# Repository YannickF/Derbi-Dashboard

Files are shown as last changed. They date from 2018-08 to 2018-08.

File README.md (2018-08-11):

# Derbi-Dashboard
Tableau de bord pour moto 50 cm3 Derbi Senda (ou "équivalent)

Le circuit imprimé est le même pour les 3 parties, mais il y a eu quelques oublis
Compteur en 3 parties indépendantes, chacune avec un écran OLED 1.3''
- compteur de vitesse (capteure inductif fixé sur la fourche et qui détecte le passage des têtes de vis du disque de frein). Le compteur kilométrique est stockéen EEPROM. Le compteur journalier est remis à zéro à chaque démarrage)
- compte-tours : fil issu de l'alternateur, avec diode de redressement
- voyants : phares / clignotants / niveau huile (flotteur installé dans le réservoir) / température / essence (avec le capteur d'origine toujours cablé avec son ampoule car il ne fonctionne pas sans)

Oublis sur le circuit imprimé : 
- diviseur de tension par 2 (2 résistances de 10 kohms) sur le fil du feu de route

REMARQUE : le circuit électrique de la moto a été légèrement modifié
- le 12V alternatif (pour les feux) est maintenant sur le 12V issu du régulateur (l'éclairage est stable même au ralenti)
- le 12 alternatif est utilisé pour le compte-tour mais il est redressé simple alternance (une diode) avant d'aller au tableau de bord. Ce signal n'est pas assez propre au ralenti pour être exploité mais il va très bien pour le reste du temps.
- le capteur de niveau d'huile n'est plus utilisé, un flotteur (on/off) est installé sur le bocal (on peut sans doute s'inspirer de la gestion du niveau d'essence pour faire fonctionner le capteur d'origine)

FONCTIONNEMENT DES CAPTEURS
Les capteurs d'huile et d'essence ne fonctionnent pas sans l'ampoule.
Pour l'essence, j'ai mesuré les tensions suivantes (mesurées entre la masse et le point milieu)
  - réservoir vide : environ 5 à 6 V (ce qui laisse 6V pour l'ampoule qui brille un peu)
  - réservoir plein : environ 8 V (il reste donc 4V pour l'ampoule, ce qui est insuffisant)

+12V. ---------
              |
              |
            Ampoule
              |
              |----------------- mesure de la tension
              |
            Capteur
              |
              |
 0V -----------

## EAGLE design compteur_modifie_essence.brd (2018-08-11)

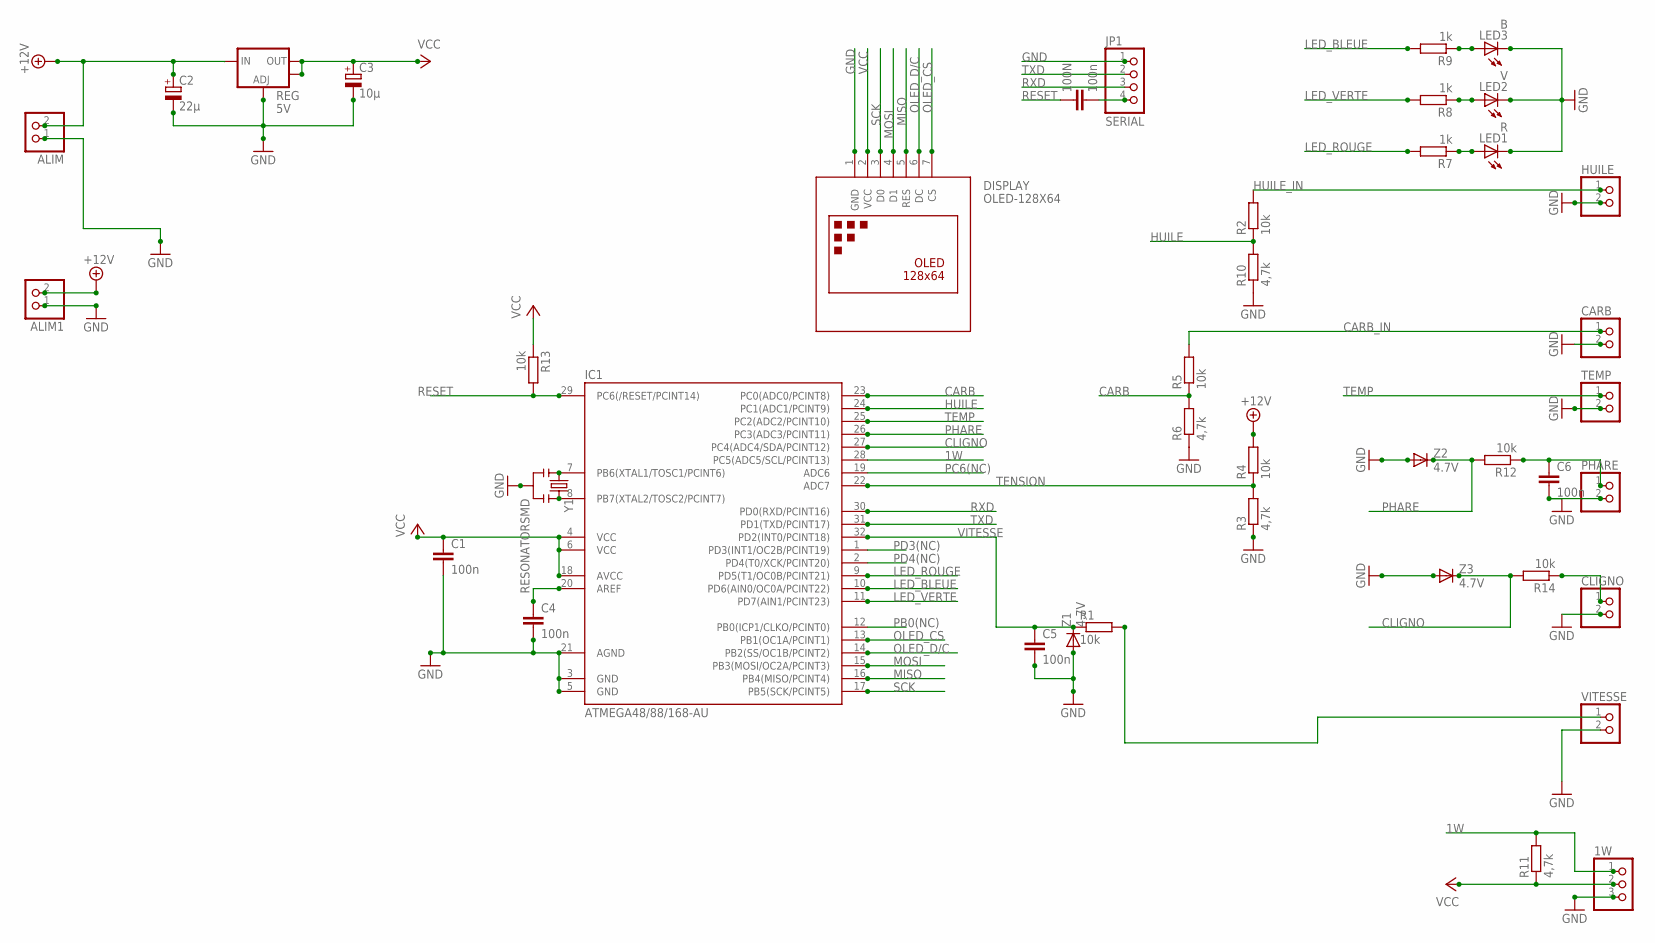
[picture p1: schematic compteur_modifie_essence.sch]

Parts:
1W: PINHD-1X3CB; 1X03-CLEANBIG
100N: 100n; C1206
ALIM, ALIM1: PINHD-1X2; 1X02
C1, C4, C5, C6: 100n; C1206
C2: 22µ; SMC_D
C3: 10µ; SMC_C
CARB: PINHD-1X2; 1X02
CLIGNO: PINHD-1X2; 1X02
DISPLAY: OLED-128X64; DISPLAY-OLED-128X64
HUILE: PINHD-1X2; 1X02
IC1: ATMEGA48/88/168-AU; TQFP32-08
JP1: SERIAL; 1X04_ROUND
LED1: R; LED5MM
LED2: V; LED5MM
LED3: B; LED5MM
PHARE: PINHD-1X2; 1X02
R1, R2, R4, R5, R12, R13, R14: 10k; R1206
R3, R6, R10, R11: 4,7k; R1206
R7, R8, R9: 1k; R1206
REG: 5V; SOT223
TEMP: PINHD-1X2; 1X02
VITESSE: PINHD-1X2; 1X02
Y1: RESONATORSMD; RESONATOR-SMD
Z1, Z2, Z3: 4.7V; SOD123

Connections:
1W: 1W.1, IC1.28 (PC5(ADC5/SCL/PCINT13)), R11.2
+12V: ALIM.2, ALIM1.2, C2.+, R4.2, REG.3 (IN)
AREF: C4.1, IC1.20 (AREF)
CARB: IC1.23 (PC0(ADC0/PCINT8)), R5.1, R6.2
CARB_IN: CARB.1, R5.2
CLIGNO: IC1.27 (PC4(ADC4/SDA/PCINT12)), R14.2, Z3.C
GND: 1W.3, ALIM.1, ALIM1.1, C1.2, C2.-, C3.-, C4.2, C5.2, C6.2, CARB.2, CLIGNO.2, DISPLAY.1 (GND), HUILE.2, IC1.3 (GND), IC1.5 (GND), IC1.21 (AGND), JP1.1, LED1.K (C), LED2.K (C), LED3.K (C), PHARE.2, R3.1, R6.1, R10.1, REG.1 (ADJ), TEMP.2, VITESSE.2, Y1.2, Z1.A, Z2.A, Z3.A
HUILE: IC1.24 (PC1(ADC1/PCINT9)), R2.1, R10.2
HUILE_IN: HUILE.1, R2.2
LED_BLEUE: IC1.10 (PD6(AIN0/OC0A/PCINT22)), R9.2
LED_ROUGE: IC1.9 (PD5(T1/OC0B/PCINT21)), R7.2
LED_VERTE: IC1.11 (PD7(AIN1/PCINT23)), R8.2
MISO: DISPLAY.5 (RES), IC1.16 (PB4(MISO/PCINT4))
MOSI: DISPLAY.4 (D1), IC1.15 (PB3(MOSI/OC2A/PCINT3))
unnamed: LED1.A, R7.1
unnamed: CLIGNO.1, R14.1
OLED_CS: DISPLAY.7 (CS), IC1.13 (PB1(OC1A/PCINT1))
OLED_D/C: DISPLAY.6 (DC), IC1.14 (PB2(SS/OC1B/PCINT2))
PB0(NC): IC1.12 (PB0(ICP1/CLKO/PCINT0))
PC6(NC): IC1.19 (ADC6)
PD3(NC): IC1.1 (PD3(INT1/OC2B/PCINT19))
PD4(NC): IC1.2 (PD4(T0/XCK/PCINT20))
PHARE: IC1.26 (PC3(ADC3/PCINT11)), R12.2, Z2.C
PHARE_IN: C6.1, PHARE.1, R12.1
R8: LED2.A, R8.1
R9: LED3.A, R9.1
RESET: 100N.1, IC1.29 (PC6(/RESET/PCINT14)), R13.2
RST: 100N.2, JP1.4
RXD: IC1.30 (PD0(RXD/PCINT16)), JP1.3
SCK: DISPLAY.3 (D0), IC1.17 (PB5(SCK/PCINT5))
TEMP: IC1.25 (PC2(ADC2/PCINT10)), TEMP.1
TENSION: IC1.22 (ADC7), R3.2, R4.1
TXD: IC1.31 (PD1(TXD/PCINT17)), JP1.2
VCC: 1W.2, C1.1, C3.+, DISPLAY.2 (VCC), IC1.4 (VCC), IC1.6 (VCC), IC1.18 (AVCC), R11.1, R13.1, REG.2 (OUT), REG.4 (OUT)
VITESSE: C5.1, IC1.32 (PD2(INT0/PCINT18)), R1.1, Z1.C
VITESS_IN: R1.2, VITESSE.1
XTAL1: IC1.7 (PB6(XTAL1/TOSC1/PCINT6)), Y1.1
XTAL2: IC1.8 (PB7(XTAL2/TOSC2/PCINT7)), Y1.3

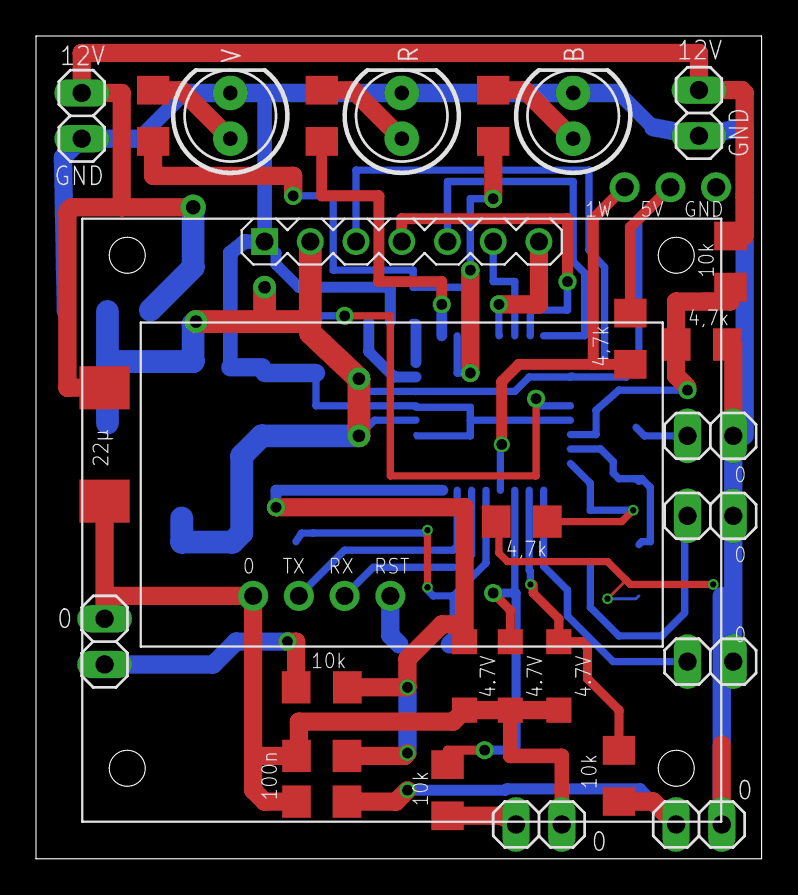
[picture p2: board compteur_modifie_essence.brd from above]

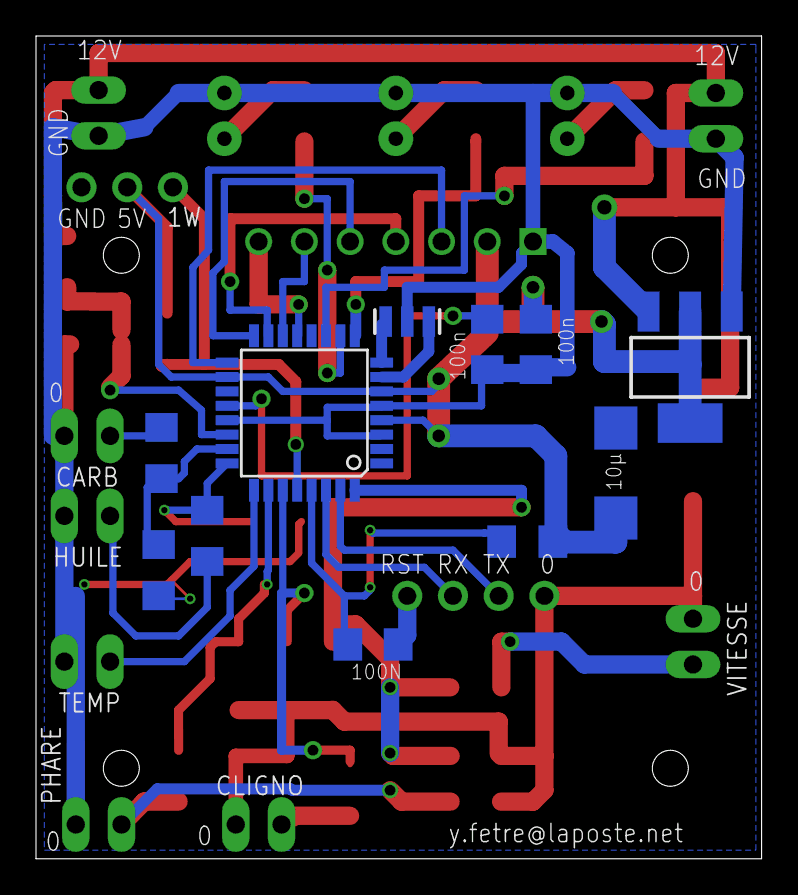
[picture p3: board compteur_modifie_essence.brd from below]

Board: 2 copper layers, 40.3 x 45.7 mm, 41 parts (12 on the bottom side), 34 nets.

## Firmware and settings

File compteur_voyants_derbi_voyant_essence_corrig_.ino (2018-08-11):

#include <Arduino.h>
#include <SPI.h>
#include <U8g2lib.h>
#include <avr/interrupt.h>
#include <OneWire.h>

#define MAX_TEMP 30 // temperature maximum pour le capteur 1W -> allumera le voyant si valeur dépassée
#define BATT_MAX 15.0  //tension maxi de la batterie
#define BATT_MIN 10.5  //tension mini de la batterie
#define ALLUME_ESSENCE_VIDE 550 // niveau du convertisseur Analogique numerique qui permet de basculer le voyant d'essence sur ON ou OFF
#define ALLUME_ESSENCE_PLEIN 750 // niveau d'essence PLEIN

#define pin_tension 7
#define pin_phare    A3
#define pin_cligno   A4
#define pin_essence  0
#define pin_huile    A1
#define pin_eau      A2
#define led_rouge    5
#define led_bleue    6
#define led_verte    7
#define BROCHE_ONEWIRE A5

//#define TEMPERATURE   //presence d'une sonde DS18B20
//#define DEBUG

//Pour l'huile, la température d'eau et le carburant, il y a de temps en temps des allumage intempestifs
// si le nombre de micro-allumages des voyants (consécutifs) atteint cette valeur, alors le voyant sera allumée pour de bon
#define COMPT_VOYANT_huile_MAX 20
#define COMPT_VOYANT_eau_MAX 20
#define COMPT_VOYANT_essence_MAX 20
#define COMPT_VOYANT_batt_MAX 20
unsigned char COMPT_VOYANT_huile=0;
unsigned char COMPT_VOYANT_eau=0;
unsigned char COMPT_VOYANT_essence=0;
unsigned char COMPT_VOYANT_batt=0;


/* Code de retour de la fonction getTemperature() */
enum DS18B20_RCODES {
  READ_OK,  // Lecture ok
  NO_SENSOR_FOUND,  // Pas de capteur
  INVALID_ADDRESS,  // Adresse reçue invalide
  INVALID_SENSOR  // Capteur invalide (pas un DS18B20)
};
/* Création de l'objet OneWire pour manipuler le bus 1-Wire */
OneWire ds(BROCHE_ONEWIRE);


unsigned int temp=0;
float tension=0;
float temperature=0;
float essence_f=0; // valeur pour mesurer le "niveau" d'essence (le capteur associé à l'ampoule donne une tension en fonction du niveau, il faut donc utiliser le convertisseur analogique/numerique
signed int temperature_int=0;
boolean phare = false;
boolean cligno = false;
boolean essence = false;
boolean essence_pre_alerte = false;
boolean huile= false;
boolean capt_eau=false;
boolean eau = false;
boolean batterie = false;
boolean aff_alertes=false;  // pour faire clignoter les icones

#define huile_width 40
#define huile_height 20
static unsigned char huile_bits[] = {
   0x00, 0x00, 0x00, 0x00, 0x00, 0x00, 0x00, 0x00, 0x00, 0x00, 0x00, 0x00,
   0x00, 0x00, 0x00, 0x00, 0x00, 0x00, 0x00, 0x00, 0x38, 0x00, 0x00, 0x00,
   0x00, 0xec, 0x01, 0x00, 0x00, 0x00, 0x86, 0xf7, 0x07, 0x00, 0x02, 0x06,
   0xc6, 0x00, 0x80, 0x0f, 0x3c, 0xfe, 0x1f, 0xe0, 0x0f, 0xe0, 0xfe, 0x3f,
   0xf8, 0x01, 0x80, 0xff, 0x7f, 0xde, 0x10, 0x00, 0x06, 0xe0, 0x67, 0x10,
   0x00, 0x06, 0xc0, 0x31, 0x38, 0x00, 0x06, 0x80, 0x18, 0x38, 0x00, 0x06,
   0x00, 0x0c, 0x38, 0x00, 0x06, 0x00, 0x06, 0x00, 0x00, 0xfe, 0xff, 0x03,
   0x00, 0x00, 0xfe, 0xff, 0x01, 0x00, 0x00, 0x00, 0x00, 0x00, 0x00, 0x00,
   0x00, 0x00, 0x00, 0x00 };
#define eau_width 31
#define eau_height 31
static unsigned char eau_bits[] = {
   0x00, 0x00, 0x00, 0x00, 0x00, 0x80, 0x00, 0x00, 0x00, 0xc0, 0x01, 0x00,
   0x00, 0xc0, 0x01, 0x00, 0x00, 0xc0, 0x01, 0x00, 0x00, 0xc0, 0xff, 0x00,
   0x00, 0xc0, 0xff, 0x00, 0x00, 0xc0, 0x01, 0x00, 0x00, 0xc0, 0x01, 0x00,
   0x00, 0xc0, 0x01, 0x00, 0x00, 0xc0, 0xff, 0x00, 0x00, 0xc0, 0xff, 0x00,
   0x00, 0xc0, 0x01, 0x00, 0x00, 0xc0, 0x01, 0x00, 0x00, 0xc0, 0x01, 0x00,
   0x00, 0xc0, 0xff, 0x00, 0x00, 0xc0, 0xff, 0x00, 0x00, 0xc0, 0x01, 0x00,
   0x00, 0xc0, 0x01, 0x00, 0x08, 0xc0, 0x01, 0x08, 0x3e, 0xe2, 0x23, 0x3e,
   0xff, 0xf3, 0xe7, 0x7f, 0xc3, 0xf3, 0xe7, 0x63, 0x00, 0xe0, 0x03, 0x00,
   0x00, 0xc0, 0x01, 0x00, 0x08, 0x08, 0x08, 0x08, 0x1c, 0x1c, 0x1c, 0x1c,
   0xfc, 0xff, 0xff, 0x1f, 0xe0, 0xe3, 0xe3, 0x03, 0x80, 0x80, 0x80, 0x00,
   0x00, 0x00, 0x00, 0x00 };
#define essence_width 30
#define essence_height 30
static unsigned char essence_bits[] = {
   0x00, 0x00, 0x00, 0x00, 0x00, 0x00, 0x00, 0x00, 0xf0, 0xff, 0xf7, 0x01,
   0xf0, 0xff, 0xc7, 0x03, 0xf0, 0xff, 0x87, 0x07, 0x30, 0x00, 0x06, 0x07,
   0x30, 0x00, 0x06, 0x0f, 0x30, 0x00, 0x86, 0x0f, 0x30, 0x00, 0x86, 0x0f,
   0x30, 0x00, 0x06, 0x0f, 0x30, 0x00, 0x06, 0x0e, 0x30, 0x00, 0x7e, 0x0e,
   0x70, 0x00, 0x7f, 0x0e, 0xf0, 0xff, 0xe7, 0x0e, 0xf0, 0xff, 0xe7, 0x0e,
   0xf0, 0xff, 0xe7, 0x0e, 0xf0, 0xff, 0xe7, 0x0e, 0xf0, 0xff, 0xe7, 0x0e,
   0xf0, 0xff, 0xe7, 0x0e, 0xf0, 0xff, 0xe7, 0x0e, 0xf0, 0xff, 0xe7, 0x0e,
   0xf0, 0xff, 0xe7, 0x0e, 0xf0, 0xff, 0xe7, 0x0e, 0xf0, 0xff, 0xe7, 0x0f,
   0xf0, 0xff, 0xc7, 0x07, 0xf8, 0xff, 0x0f, 0x01, 0xfc, 0xff, 0x1f, 0x00,
   0xfc, 0xff, 0x1f, 0x00, 0x00, 0x00, 0x00, 0x00, 0x00, 0x00, 0x00, 0x00 };

#define cligno_width 40
#define cligno_height 26
static unsigned char cligno_bits[] = {
   0x00, 0x00, 0x00, 0x00, 0x00, 0x00, 0x00, 0x00, 0x00, 0x00, 0x00, 0x00,
   0x00, 0x00, 0x00, 0x00, 0x0c, 0x00, 0x30, 0x00, 0x00, 0x0e, 0x00, 0x70,
   0x00, 0x00, 0x0f, 0x00, 0xf0, 0x00, 0x80, 0xfd, 0xc3, 0xbf, 0x01, 0xc0,
   0xfc, 0xc3, 0x3f, 0x03, 0x60, 0x00, 0x42, 0x00, 0x06, 0x30, 0x00, 0x42,
   0x00, 0x0c, 0x18, 0x00, 0x42, 0x00, 0x18, 0x0c, 0x00, 0x42, 0x00, 0x30,
   0x06, 0x00, 0x42, 0x00, 0x60, 0x06, 0x00, 0x42, 0x00, 0x60, 0x0c, 0x00,
   0x42, 0x00, 0x30, 0x18, 0x00, 0x42, 0x00, 0x18, 0x30, 0x00, 0x42, 0x00,
   0x0c, 0x60, 0x00, 0x42, 0x00, 0x06, 0xc0, 0xfc, 0xc3, 0x3f, 0x03, 0x80,
   0xfd, 0xc3, 0xbf, 0x01, 0x00, 0x0f, 0x00, 0xf0, 0x00, 0x00, 0x0e, 0x00,
   0x70, 0x00, 0x00, 0x0c, 0x00, 0x30, 0x00, 0x00, 0x00, 0x00, 0x00, 0x00,
   0x00, 0x00, 0x00, 0x00, 0x00, 0x00, 0x00, 0x00, 0x00, 0x00 };
#define phare_width 40
#define phare_height 29
static unsigned char phare_bits[] = {
   0x00, 0x00, 0x00, 0x00, 0x00, 0x00, 0x00, 0x80, 0x03, 0x00, 0x00, 0x00,
   0xe0, 0x0f, 0x00, 0xfc, 0x3f, 0xf8, 0x7f, 0x00, 0xfc, 0x3f, 0x3c, 0xf8,
   0x01, 0x00, 0x00, 0x1e, 0xe0, 0x03, 0x00, 0x00, 0x06, 0x80, 0x07, 0x00,
   0x00, 0x06, 0x00, 0x0f, 0xfc, 0x3f, 0x07, 0x00, 0x1c, 0xfc, 0x3f, 0x07,
   0x00, 0x1c, 0x00, 0x00, 0x03, 0x00, 0x38, 0x00, 0x00, 0x03, 0x00, 0x30,
   0x00, 0x00, 0x03, 0x00, 0x30, 0xfc, 0x3f, 0x03, 0x00, 0x30, 0xfc, 0x3f,
   0x03, 0x00, 0x30, 0x00, 0x00, 0x03, 0x00, 0x30, 0x00, 0x00, 0x03, 0x00,
   0x38, 0x00, 0x00, 0x03, 0x00, 0x18, 0xfc, 0x3f, 0x07, 0x00, 0x1c, 0xfc,
   0x3f, 0x07, 0x00, 0x0e, 0x00, 0x00, 0x06, 0x00, 0x07, 0x00, 0x00, 0x0e,
   0xc0, 0x03, 0x00, 0x00, 0x1c, 0xf8, 0x01, 0xfc, 0x3f, 0xf8, 0x7f, 0x00,
   0xfc, 0x3f, 0xf0, 0x1f, 0x00, 0x00, 0x00, 0x00, 0x00, 0x00, 0x00, 0x00,
   0x00, 0x00, 0x00, 0x00, 0x00, 0x00, 0x00, 0x00, 0x00, 0x00, 0x00, 0x00,
   0x00 };
#define croisement_width 40
#define croisement_height 29
static unsigned char croisement_bits[] = {
   0x00, 0x00, 0x00, 0x00, 0x00, 0x00, 0x00, 0x80, 0x03, 0x00, 0x00, 0x00,
   0xe0, 0x0f, 0x00, 0x00, 0x38, 0xf8, 0x7f, 0x00, 0x00, 0x3e, 0x3c, 0xf8,
   0x01, 0xc0, 0x0f, 0x1e, 0xe0, 0x03, 0xf0, 0x03, 0x06, 0x80, 0x07, 0x7c,
   0x00, 0x06, 0x00, 0x0f, 0x0e, 0x38, 0x07, 0x00, 0x1c, 0x00, 0x3e, 0x07,
   0x00, 0x1c, 0xc0, 0x0f, 0x03, 0x00, 0x38, 0xf0, 0x03, 0x03, 0x00, 0x30,
   0x7c, 0x00, 0x03, 0x00, 0x30, 0x0e, 0x38, 0x03, 0x00, 0x30, 0x00, 0x3e,
   0x03, 0x00, 0x30, 0xc0, 0x0f, 0x03, 0x00, 0x30, 0xf0, 0x03, 0x03, 0x00,
   0x38, 0x7c, 0x00, 0x03, 0x00, 0x18, 0x0e, 0x38, 0x07, 0x00, 0x1c, 0x00,
   0x3e, 0x07, 0x00, 0x0e, 0xc0, 0x0f, 0x06, 0x00, 0x07, 0xf0, 0x03, 0x0e,
   0xc0, 0x03, 0x7c, 0x00, 0x1c, 0xf8, 0x01, 0x0e, 0x38, 0xf8, 0x7f, 0x00,
   0x00, 0x3e, 0xf0, 0x1f, 0x00, 0xc0, 0x0f, 0x00, 0x00, 0x00, 0xf0, 0x03,
   0x00, 0x00, 0x00, 0x7c, 0x00, 0x00, 0x00, 0x00, 0x0e, 0x00, 0x00, 0x00,
   0x00 };
#define batterie_width 28
#define batterie_height 21
static unsigned char batterie_bits[] = {
   0x00, 0x00, 0x00, 0x00, 0x00, 0x00, 0x00, 0x00, 0xe0, 0x01, 0x78, 0x00,
   0xe0, 0x01, 0x78, 0x00, 0xe0, 0x01, 0x78, 0x00, 0xfc, 0xff, 0xff, 0x03,
   0xfc, 0xff, 0xff, 0x03, 0xfc, 0xff, 0xff, 0x03, 0xfc, 0xff, 0xff, 0x03,
   0xfc, 0xff, 0xcf, 0x03, 0xfc, 0xff, 0xcf, 0x03, 0x0c, 0xfc, 0x03, 0x03,
   0x0c, 0xfc, 0x03, 0x03, 0xfc, 0xff, 0xcf, 0x03, 0xfc, 0xff, 0xcf, 0x03,
   0xfc, 0xff, 0xff, 0x03, 0xfc, 0xff, 0xff, 0x03, 0xfc, 0xff, 0xff, 0x03,
   0xfc, 0xff, 0xff, 0x03, 0x00, 0x00, 0x00, 0x00, 0x00, 0x00, 0x00, 0x00 };





/* Constructor */
U8G2_SH1106_128X64_NONAME_1_4W_HW_SPI u8g2(U8G2_R0, /* cs=*/ 9, /* dc=*/ 10, /* reset=*/ 12);  //CS non connecté en réalité



/* u8g2.begin() is required and will sent the setup/init sequence to the display */
void setup(void) {
#ifdef DEBUG
  Serial.begin(57600);  // meme débit que le bootloader (old)
#endif
  // configuration des broches en entrées / sorties
  analogReference(DEFAULT);
  pinMode(pin_tension,INPUT);
  pinMode(pin_phare,INPUT);
  pinMode(pin_cligno,INPUT);
  pinMode(pin_essence,INPUT);
  pinMode(pin_huile,INPUT_PULLUP);
  pinMode(pin_eau,INPUT_PULLUP);
  pinMode(led_rouge,OUTPUT);
  pinMode(led_bleue,OUTPUT);
  pinMode(led_verte,OUTPUT);

  // réduction de la résolution du DS18B20
  setResolution9bits();

  // paramétrage de l'écran OLED
  u8g2.begin();
  // animation de boot
  for (int i=0;i<65;i++) {
    u8g2.firstPage();
    do {
      u8g2.drawBox(64-i,0,2*i,64);
    } while ( u8g2.nextPage() );
  }
  for (int i=65;i>=0;i--) {
    u8g2.firstPage();
    do {
      u8g2.drawBox(64-i,0,2*i,64);
    } while ( u8g2.nextPage() );
  }


  // test des LED
  digitalWrite(led_verte,HIGH);
  delay(250);
  digitalWrite(led_rouge,HIGH);
  delay(250);
  digitalWrite(led_bleue,HIGH);
  delay(500);
  digitalWrite(led_bleue,LOW);
  delay(250);
  digitalWrite(led_rouge,LOW);
  delay(250);
  digitalWrite(led_verte,LOW);
}

/* draw something on the display with the `firstPage()`/`nextPage()` loop*/
void loop(void) {
#ifdef TEMPERATURE
   // Lecture de la température via sonde DS18B20
   if (getTemperature(&temperature, true) != READ_OK) {
     temperature=-99;
      return;
   }
#else
  temperature=99;
#endif

   //  lecture de la tension, on fait la moyenne sur 16 lectures
   temp=0;
   for (char i=0;i<=15;i++) {
    temp+=analogRead(pin_tension);
   }
   tension=(float) (temp / 16)  ;
   tension = tension* 0.015272;  // c'est le coefficient du convertisseur ADC

  //  lecture du niveau d'essence, on fait la moyenne sur 16 lectures (on pourrait le faire en même temps que pour la tension)
   temp=0;
   for (char i=0;i<=15;i++) {
    temp+=analogRead(pin_essence); 
   }
   essence_f=(float) (temp / 16)  ;
   if (essence_f <= ALLUME_ESSENCE_VIDE) {essence=true; essence_pre_alerte=false;}
   else if (essence_f >= ALLUME_ESSENCE_PLEIN) {essence=false; essence_pre_alerte=false;}
   else {essence=false; essence_pre_alerte=true;}
   
 #ifdef DEBUG
  Serial.print("Essence : ");
  Serial.println(essence_f);
  Serial.print("Alerte : ");
  Serial.println(essence);
  Serial.print("Pre-Alerte : ");
  Serial.println(essence_pre_alerte);
  Serial.println();
 #endif
  // lecture des états des broches
  phare=digitalRead(pin_phare);
  cligno=digitalRead(pin_cligno);
  //essence=!digitalRead(pin_essence);
  huile=!digitalRead(pin_huile);
  capt_eau=!digitalRead(pin_eau);

  // TEST pour éviter les déclenchement intempestifs des alertes
  if (essence) {
    COMPT_VOYANT_essence++;
    if (COMPT_VOYANT_essence < COMPT_VOYANT_essence_MAX) {essence=false;}
  }
  else {
    COMPT_VOYANT_essence=0;
  }
  if (huile) {
    COMPT_VOYANT_huile++;
    if (COMPT_VOYANT_huile < COMPT_VOYANT_huile_MAX) {huile=false;}
  }
  else {
    COMPT_VOYANT_huile=0;
  }
  if (capt_eau) {
    COMPT_VOYANT_eau++;
    if (COMPT_VOYANT_eau < COMPT_VOYANT_eau_MAX) {capt_eau=false;}
  }
  else {
    COMPT_VOYANT_eau=0;
  }
  if ((tension > BATT_MAX) or (tension < BATT_MIN)) {
    COMPT_VOYANT_batt++;
    batterie=true;
    if (COMPT_VOYANT_batt < COMPT_VOYANT_batt_MAX) {batterie=false;}
  }
  else {
    COMPT_VOYANT_batt=0;
    batterie=false;
  }

  // TEST POUR DECLENCHER LES ALERTES sur les LED
  if (phare) {digitalWrite(led_bleue,HIGH);} else {digitalWrite(led_bleue, LOW);}
  if (cligno) {digitalWrite(led_verte,HIGH);} else {digitalWrite(led_verte, LOW);}
  if (essence or huile or eau  or batterie) {digitalWrite(led_rouge,HIGH);} else {digitalWrite(led_rouge, LOW);} 
  // on n'allume pas la LED rouge en cas de pré-alerte essence
  if (capt_eau or (temperature_int >= MAX_TEMP)) {eau=true;} else {eau=false;}


  // AFFICHAGE SUR L'ECRAN
  u8g2.firstPage();
  do {
    // quadrillage
    u8g2.drawHLine(0,32,128);
    u8g2.drawVLine(42,0,64);
    u8g2.drawVLine(85,0,64);

    // affichage de la tension et de la température (sauf si voyant de batterie)
    if (batterie and aff_alertes)
    {
      u8g2.drawXBM( 50, 5, batterie_width, batterie_height, batterie_bits);
    }
    else
    {
      u8g2.setFont(u8g2_font_courB08_tf);
      u8g2.drawStr(77, 11, "V");
#ifdef TEMPERATURE
      u8g2.drawUTF8(72,26,"°C");
#endif
      u8g2.setCursor(47,11);
      u8g2.print(tension,1);
      u8g2.setCursor(55,26);
#ifdef TEMPERATURE
      temperature_int=(int) int(temperature);  // on ne garde que la partie entière de la température
      u8g2.print(temperature_int);
#endif
    }

    // affichage huile
    if (huile and aff_alertes) {u8g2.drawXBM( 44, 38, huile_width, huile_height, huile_bits);}
    // affichage eau
    if (eau and aff_alertes) {u8g2.drawXBM( 92, 33, eau_width, eau_height, eau_bits);}
    // affichage pre alerte essence (sans clignoter)
    if (essence_pre_alerte) {u8g2.drawXBM( 5, 33, essence_width, essence_height, essence_bits);}
    // affichage essence
    if (essence and aff_alertes) {u8g2.drawXBM( 5, 33, essence_width, essence_height, essence_bits);}
    //affichage cligno
    if (cligno==true) {u8g2.drawXBM( 88, 3, cligno_width, cligno_height, cligno_bits);}
    //affichage phare/croisement
    if (phare==true) {u8g2.drawXBM( 1, 1, phare_width, phare_height, phare_bits);}
    else {u8g2.drawXBM( 1, 1, croisement_width, croisement_height, croisement_bits);}
  } while ( u8g2.nextPage() );

  // on fait clignoter les voyants
  aff_alertes=!aff_alertes;
  delay(100);





}


void setResolution9bits(void) {
  byte addr[8];
  // data[] : Données lues depuis le scratchpad
  // addr[] : Adresse du module 1-Wire détecté
  ds.search(addr);
  if (addr[0] == 0x28)   // on verifie que c'est un DS18B20
  {
    Serial.print("C'est bien un DS18B20");
    // Réduction de la résolution du capteur à 9 bits
    ds.reset(); // rest 1-Wire
    ds.select(addr); // select DS18B20
    ds.write(0x4E); // write on scratchPad
    ds.write(0x00); // User byte 0 - Unused
    ds.write(0x00); // User byte 1 - Unused
    ds.write(0x1F); // set up en 9 bits (0x1F)
    ds.reset(); // reset 1-Wire
  }
}

/**
 * Fonction de lecture de la température via un capteur DS18B20.
 */
byte getTemperature(float *temperature, byte reset_search) {
  byte data[9], addr[8];
  // data[] : Données lues depuis le scratchpad
  // addr[] : Adresse du module 1-Wire détecté

  /* Reset le bus 1-Wire ci nécessaire (requis pour la lecture du premier capteur) */
  if (reset_search) {
    ds.reset_search();
  }

  /* Recherche le prochain capteur 1-Wire disponible */
  if (!ds.search(addr)) {
    // Pas de capteur
    return NO_SENSOR_FOUND;
  }

  /* Vérifie que l'adresse a été correctement reçue */
  if (OneWire::crc8(addr, 7) != addr[7]) {
    // Adresse invalide
    return INVALID_ADDRESS;
  }

  /* Vérifie qu'il s'agit bien d'un DS18B20 */
  if (addr[0] != 0x28) {
    // Mauvais type de capteur
    return INVALID_SENSOR;
  }




  /* Reset le bus 1-Wire et sélectionne le capteur */
  ds.reset();
  ds.select(addr);

  /* Lance une prise de mesure de température et attend la fin de la mesure
      On attend 100 ms au lieu de 800 puisqu'on a réduit la résolution et que cela réduit le temps de conversion
  */
  ds.write(0x44, 1);
  delay(100);

  /* Reset le bus 1-Wire, sélectionne le capteur et envoie une demande de lecture du scratchpad */
  ds.reset();
  ds.select(addr);
  ds.write(0xBE);

 /* Lecture du scratchpad */
  for (byte i = 0; i < 9; i++) {
    data[i] = ds.read();
  }

  /* Calcul de la température en degré Celsius */
  *temperature = ((data[1] << 8) | data[0]) * 0.0625;

  // Pas d'erreur
  return READ_OK;
}

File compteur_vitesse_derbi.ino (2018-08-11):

#include <Arduino.h>
#include <SPI.h>
#include <U8g2lib.h>
#include <avr/interrupt.h>
#include <EEPROM.h>

//#define DEBUG
// choix entre 2 modes de mesure de la rotation de la roue
// DETECTE_TIERS_DISQUE : on mesure un 1/3 de tour de roue grace au disque de frein (en 3 parties)
// DETECTE_TIERS_2_TETES_VIS : on mesure 1/3 de tour de roue grace au 6 vis de fixation du disque (3 paires de vis) : il y a donc des impulsions supplémentaires à gérer
#define DETECTE_TIERS_DISQUE
//#define DETECTE_TIERS_2_TETES_VIS


// pour programmer initialement le total kilométrique à la valeur de l'ancien compteur à cable
// il faudra transférer le firmware 1 fois avec ce #define, puis ensuite sans. L'EEPROM sera alors programmée avec cette valeur.
//#define INIT_COMPTEUR 10580 

#define OCIEA 1    // ce bit du registre TIMSK1 est bizarrement non défini dans Arduino, alors qu'il est documenté dans la datasheet

// périmètre de la roue en mm
const float tour_roue = 2136;
const unsigned int pulse_1kmh = 40050; // nombre de pulse d'horloge correspondant à 1, à 99, et 0 km/havec les réglages du timer ci-dessous (dans setup)
const unsigned int pulse_99kmh = 405; 
const unsigned int pulse_0kmh = 65535;
#define input_pin 2   // broche d'entrée du signal pour le compteur

// les variables pour les compteurs : (vitesse, trip, km total)
volatile unsigned int vitesse=0;
volatile float trip = 0;
volatile float total = 0;
float old_total = 0;

// variables pour mesurer le temps entre 2 impulsions
volatile unsigned int pulse;
volatile byte compte_pulse = 0;
// variables pour bien positionner l'affichage des valeurs sur l'écran (en fonction du nombre de chiffres)
unsigned char pos_vitesse = 34;
unsigned char pos_total = 8;
unsigned char pos_trip = 75;


/* Constructor */
U8G2_SH1106_128X64_NONAME_1_4W_HW_SPI u8g2(U8G2_R0, /* cs=*/ 9, /* dc=*/ 10, /* reset=*/ 12);



void calcul_vitesse(void) {
    //calcul des vitesses
   if (pulse >=pulse_99kmh) {vitesse=pulse_1kmh / pulse;} // on evite la division par 0 en cas de débordement du timer (pulse vaut 0 dans ce cas)
    else {vitesse=99;}
    if (vitesse < 10) {
      pos_vitesse = 33;
    } else {
      pos_vitesse = 4;
    }

    //calcul du trip
    if (trip > 999.9) {
      trip = 0;
    }
    if (trip <= 9.9) {
      pos_trip = 86;
    }
    if (trip >= 10) {
      pos_trip = 80;
    }
    if (trip >= 100) {
      pos_trip = 74;
    }


    //calcul du total
    if (total > 99999) {
      total = 0;
    }
    if (total > 9) {
      pos_total = 23;
    } else {
      pos_total = 29;
    }
    if (total > 99) {
      pos_total = 17;
    }
    if (total > 999) {
      pos_total = 11;
    }
    if (total > 9999) {
      pos_total = 5;
    }
}



void input_pulse(void) {

#ifdef DETECTE_TIERS_2_TETES_VIS
  compte_pulse++;
  if (compte_pulse == 1) { // c'est la 1ère impulsion, on lance le timer1 à partir de 0
    TCNT1 = 0;
  }
  if (compte_pulse == 3) {
    pulse = TCNT1;
    compte_pulse = 0;
    trip += tour_roue / 3000000 ;  // conversion mm en km + facteur 1/3 car on compte les tiers de tours de roue
    total += tour_roue / 3000000;
  }
#endif
#ifdef DETECTE_TIERS_DISQUE
    pulse=TCNT1;
    TCNT1=0;
    trip += tour_roue / 3000000 ;  // conversion mm en km + facteur 1/3 car on compte les tiers de tours de roue
    total += tour_roue / 3000000;

#endif
#ifdef DEBUG
  Serial.print("Pulse ");
  Serial.print(compte_pulse);
  Serial.print(" : ");
  Serial.println(TCNT1);
  Serial.println(total);
  Serial.println(trip);
#endif
}

//ISR(TIMER1_OVF_vect) {
//#ifdef DEBUG
//  Serial.println("OVF !");
//#endif
//}

ISR(TIMER1_COMPA_vect) {
#ifdef DEBUG
  Serial.println("COMPA !");
#endif
  // on roule très lentement !!!!
  pulse = pulse_0kmh;
  compte_pulse = 0;
  // on en profite pour mémoriser les nouvelles données (compteur total) dans l'EEPROM
  // on mémorise le total s'il a augmenté de plus de 500 m
  EEPROM.get(0, old_total);
  if (total - old_total >= 0.5) {
    old_total = total;
    EEPROM.put(0, total);
  }
#ifdef INIT_COMPTEUR
  EEPROM.put(0, (float) INIT_COMPTEUR);
#endif

}

/* u8g2.begin() is required and will sent the setup/init sequence to the display */
void setup(void) {
#ifdef DEBUG
  Serial.begin(115200);
#endif
  // on lit le compteur kilométrique total en EEPROM (adresse 0)
  EEPROM.get(0, total);
  old_total = total;

  // paramétrage de l'écran OLED
  u8g2.begin();
  // animation de boot
  for (int i=0;i<65;i++) {
    u8g2.firstPage();
    do {
      u8g2.drawBox(64-i,0,2*i,64);
    } while ( u8g2.nextPage() );
  }
  for (int i=65;i>=0;i--) {
    u8g2.firstPage();
    do {
      u8g2.drawBox(64-i,0,2*i,64);
    } while ( u8g2.nextPage() );
  }

  // on active l'interruption sur débordement du timer1 par rapport au registre OCR1A (output compare)
  TCCR1B = 0;
  TCCR1A = 0;
  OCR1A =  pulse_1kmh;   // avec un quartz à 16 MHz et prescaler 1024, cette valeur va provoquer un overflow après 2,5632s, ce qui correspond à moins de 1 km/h avec la roue de 68 cm de diamètre (on mesure 1/3 de tour de roue)
  //TIMSK1 |= (1 << TOIE1) ;
  TIMSK1 |= (1 << OCIEA) ;
  // on active le mode 4 CTC (timer1 debord quand il atteint la valeur OCR1A)
  TCCR1B |= (1 << WGM12); // mode CTC 4
  // on divise la fréquence d'horloge par 1024 @ 16 MHz : 1 tic=64 µs
  TCCR1B |= (1 << CS12);
  TCCR1B |= (1 << CS10);
  
  TCNT1=0;
  // configuration entrée/sortie et interruption
  pinMode(input_pin, INPUT_PULLUP);
  attachInterrupt(digitalPinToInterrupt(input_pin), input_pulse, FALLING);

}

/* draw something on the display with the `firstPage()`/`nextPage()` loop*/
void loop(void) {

  


  // AFFICHAGE SUR L'ECRAN

  u8g2.firstPage();

  do {

    // affichage de l'unité de mesure de la vitesse
    u8g2.setFont(u8g2_font_logisoso16_tf);
    u8g2.drawStr(75, 17, "km/h");


    // affichage dela vitesse
    u8g2.setFont(u8g2_font_logisoso50_tn);
    u8g2.setCursor(pos_vitesse, 50);
    u8g2.print(vitesse);

    // affichage des unités des compteurs kilométriques
    u8g2.setFont(u8g2_font_courB08_tf);
    u8g2.drawStr(42, 64, "km");
    u8g2.drawStr(115, 64, "km");

    // affichage du trip
    u8g2.setCursor(pos_trip, 64);
    u8g2.print(trip);

    //affichage du total
    u8g2.setCursor(pos_total, 64);
    u8g2.print((unsigned int)total);

 #ifdef DEBUG
 // pour debug : affichage du la valeur pulse
    u8g2.setCursor(70, 32);
    u8g2.print((unsigned int)pulse);
 #endif
  } while ( u8g2.nextPage() );
 
  delay(750);
  calcul_vitesse();

}

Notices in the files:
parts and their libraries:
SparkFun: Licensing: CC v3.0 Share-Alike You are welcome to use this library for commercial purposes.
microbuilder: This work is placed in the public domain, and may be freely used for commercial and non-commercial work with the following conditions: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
